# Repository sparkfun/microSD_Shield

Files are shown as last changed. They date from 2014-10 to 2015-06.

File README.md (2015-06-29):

SparkFun microSD Shield
===========================

microSD Shield

[*microSD Shield (DEV-12761)*](https://www.sparkfun.com/products/12761)

The microSD shield equips your Arduino with mass-storage capability, so you can use it for data-logging or other related projects. 

Repository Contents
-------------------

* **/Firmware** - Example .INO sketch for Arduino. Requires the SD.h library
* **/Hardware** - All Eagle design files (.brd, .sch)
* **/Production** - Test bed files and production panel files

Documentation
--------------
* **[Hookup Guide](https://learn.sparkfun.com/tutorials/microsd-shield-and-sd-breakout-hookup-guide)** - Basic hookup guide for the microSD Shield.
* **[SparkFun Fritzing repo](https://github.com/sparkfun/Fritzing_Parts)** - Fritzing diagrams for SparkFun products.
* **[SparkFun 3D Model repo](https://github.com/sparkfun/3D_Models)** - 3D models of SparkFun products. 

Product Versions
----------------
* [DEV-09802](https://www.sparkfun.com/products/9802)- Hardware version 1.3. Designed for Uno (not R3)

Version History
---------------
* [v1.3](https://github.com/sparkfun/microSD_Shield/tree/V_1.3) Version 1.3

License Information
-------------------

This product is _**open source**_! 

Please review the LICENSE.md file for license information. 

If you have any questions or concerns on licensing, please contact techsupport@sparkfun.com.

Distributed as-is; no warranty is given.

- Your friends at SparkFun.

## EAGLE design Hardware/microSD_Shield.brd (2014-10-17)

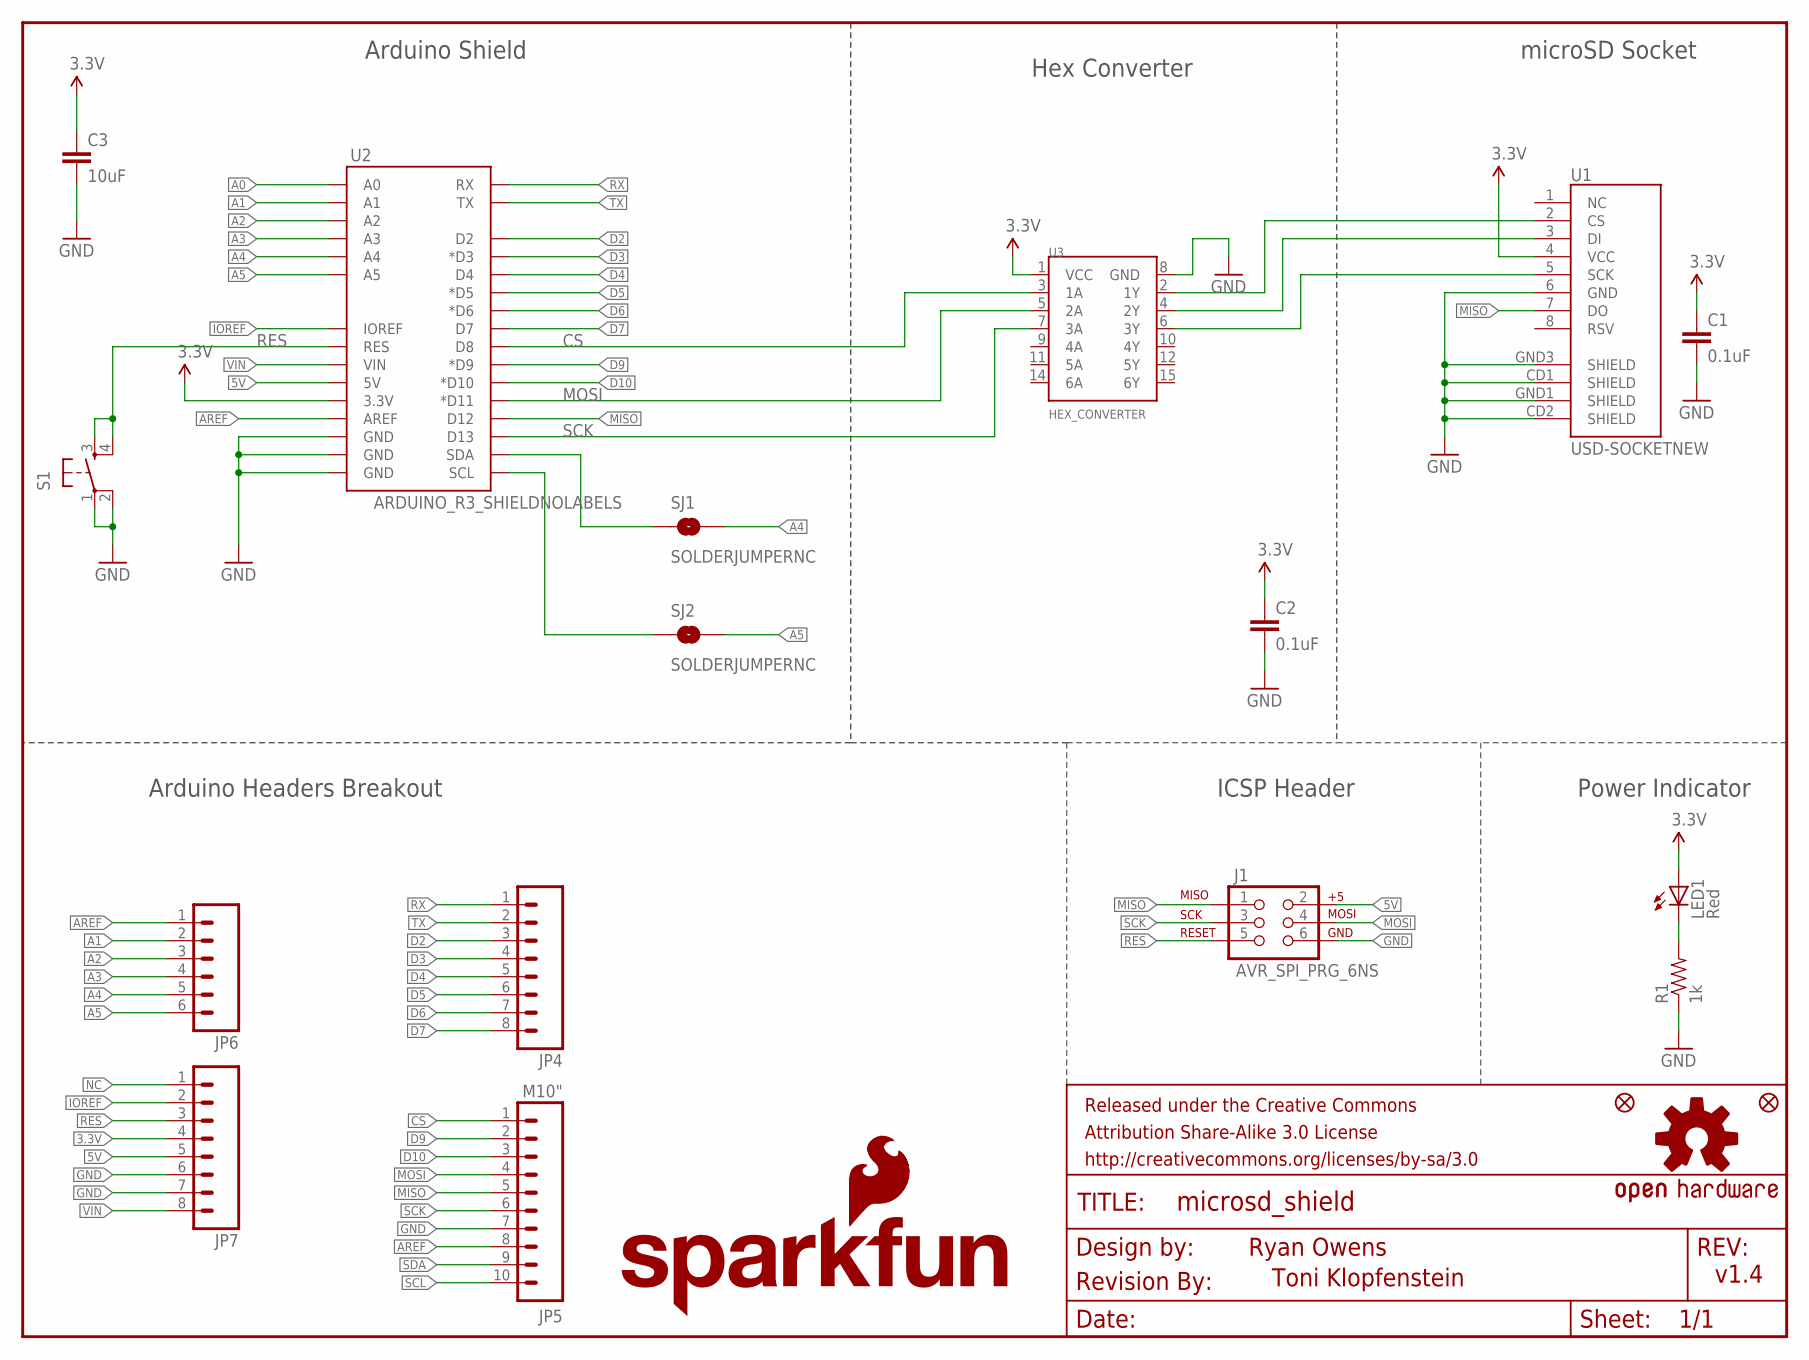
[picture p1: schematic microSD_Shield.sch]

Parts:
C1, C2: 0.1uF; 0603-CAP
C3: 10uF; 0603-CAP
FRAME1: FRAME-LETTER; CREATIVE_COMMONS
J1: AVR_SPI_PRG_6NS; 2X3-NS
JP1: SFE_LOGO_NAME_FLAME.1_INCH; SFE_LOGO_NAME_FLAME_.1
JP2, JP3: FIDUCIAL1X2; FIDUCIAL-1X2
JP4: M08; 1X08
JP5: M10"; 1X10
JP6: M06SIP; 1X06
JP7: M081X08; 1X08
LED1: Red; LED-0603
LOGO1: OSHW-LOGOM; OSHW-LOGO-M
LOGO2: SFE_LOGO_FLAME.6_INCH; SFE_LOGO_FLAME_.6
R1: 1k; 0603-RES
S1: TAC_SWITCHSMD; TACTILE_SWITCH_SMD
SJ1, SJ2: SOLDERJUMPERNC; SJ_2S
U1: USD-SOCKETNEW; MICRO-SD-SOCKET-PP
U2: ARDUINO_R3_SHIELDNOLABELS; UNO_R3_SHIELD_NOLABELS
U3: HEX_CONVERTER; SO016
U$1: REVISION

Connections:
3.3V: C1.1, C2.1, C3.1, JP7.4, LED1.A, U1.4 (VCC), U2.3.3V, U3.1 (VCC)
5V: J1.2, JP7.5, U2.5V
A0: JP6.1, U2.A0
A1: JP6.2, U2.A1
A2: JP6.3, U2.A2
A3: JP6.4, U2.A3
A4: JP6.5, SJ1.2, U2.A4
A5: JP6.6, SJ2.2, U2.A5
AREF: JP5.8, U2.AREF
CS: JP5.1, U2.D8, U3.3 (1A)
D2: JP4.3, U2.D2
D3: JP4.4, U2.D3 (*D3)
D4: JP4.5, U2.D4
D5: JP4.6, U2.D5 (*D5)
D6: JP4.7, U2.D6 (*D6)
D7: JP4.8, U2.D7
D9: JP5.2, U2.D9 (*D9)
D10: JP5.3, U2.D10 (*D10)
GND: C1.2, C2.2, C3.2, J1.6, JP5.7, JP7.6, JP7.7, R1.1, S1.1, S1.2, U1.6 (GND), U1.CD1 (SHIELD), U1.CD2 (SHIELD), U1.GND1 (SHIELD), U1.GND3 (SHIELD), U2.GND@0 (GND), U2.GND@1 (GND), U2.GND@2 (GND), U3.8 (GND)
IOREF: JP7.2, U2.IOREF
MISO: J1.1, JP5.5, U1.7 (DO), U2.D12
MOSI: J1.4, JP5.4, U2.D11 (*D11), U3.5 (2A)
unnamed: U1.3 (DI), U3.4 (2Y)
unnamed: U1.5 (SCK), U3.6 (3Y)
unnamed: LED1.C, R1.2
unnamed: U1.2 (CS), U3.2 (1Y)
NC: JP7.1
RES: J1.5, JP7.3, S1.3, S1.4, U2.RES
RX: JP4.1, U2.RX
SCK: J1.3, JP5.6, U2.D13, U3.7 (3A)
SCL: JP5.10, SJ2.1, U2.SCL
SDA: JP5.9, SJ1.1, U2.SDA
TX: JP4.2, U2.TX
VIN: JP7.8, U2.VIN

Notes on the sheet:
Power Indicator
Ryan Owens
v1.4
Toni Klopfenstein
Arduino Headers Breakout
ICSP Header
microSD Socket
Hex Converter
Arduino Shield

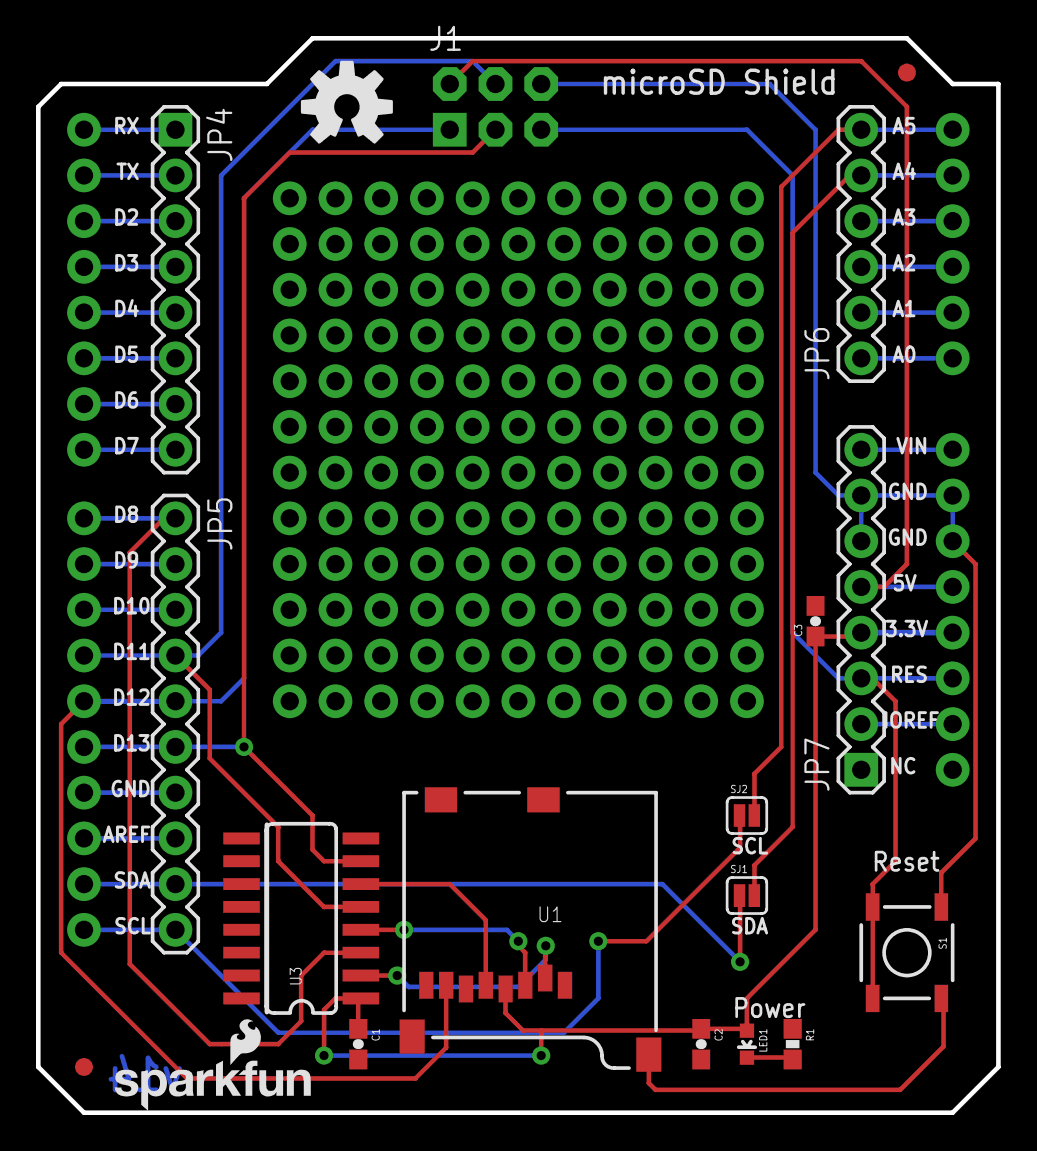
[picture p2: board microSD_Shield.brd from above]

Board: 2 copper layers, 53.3 x 59.7 mm, 23 parts (1 on the bottom side), 33 nets.

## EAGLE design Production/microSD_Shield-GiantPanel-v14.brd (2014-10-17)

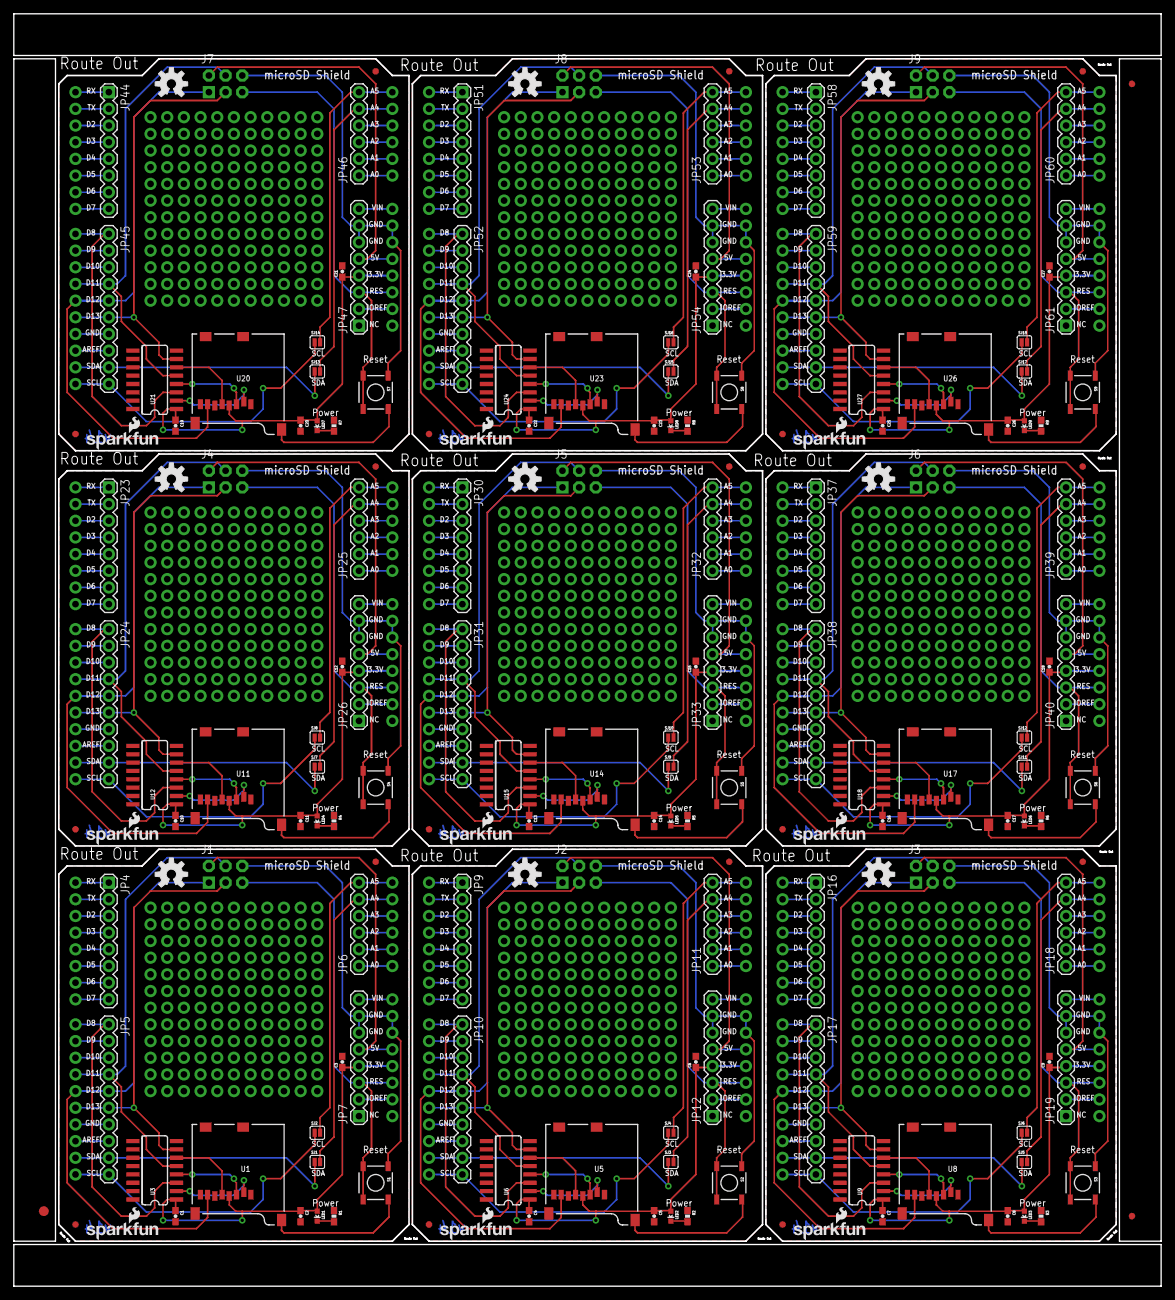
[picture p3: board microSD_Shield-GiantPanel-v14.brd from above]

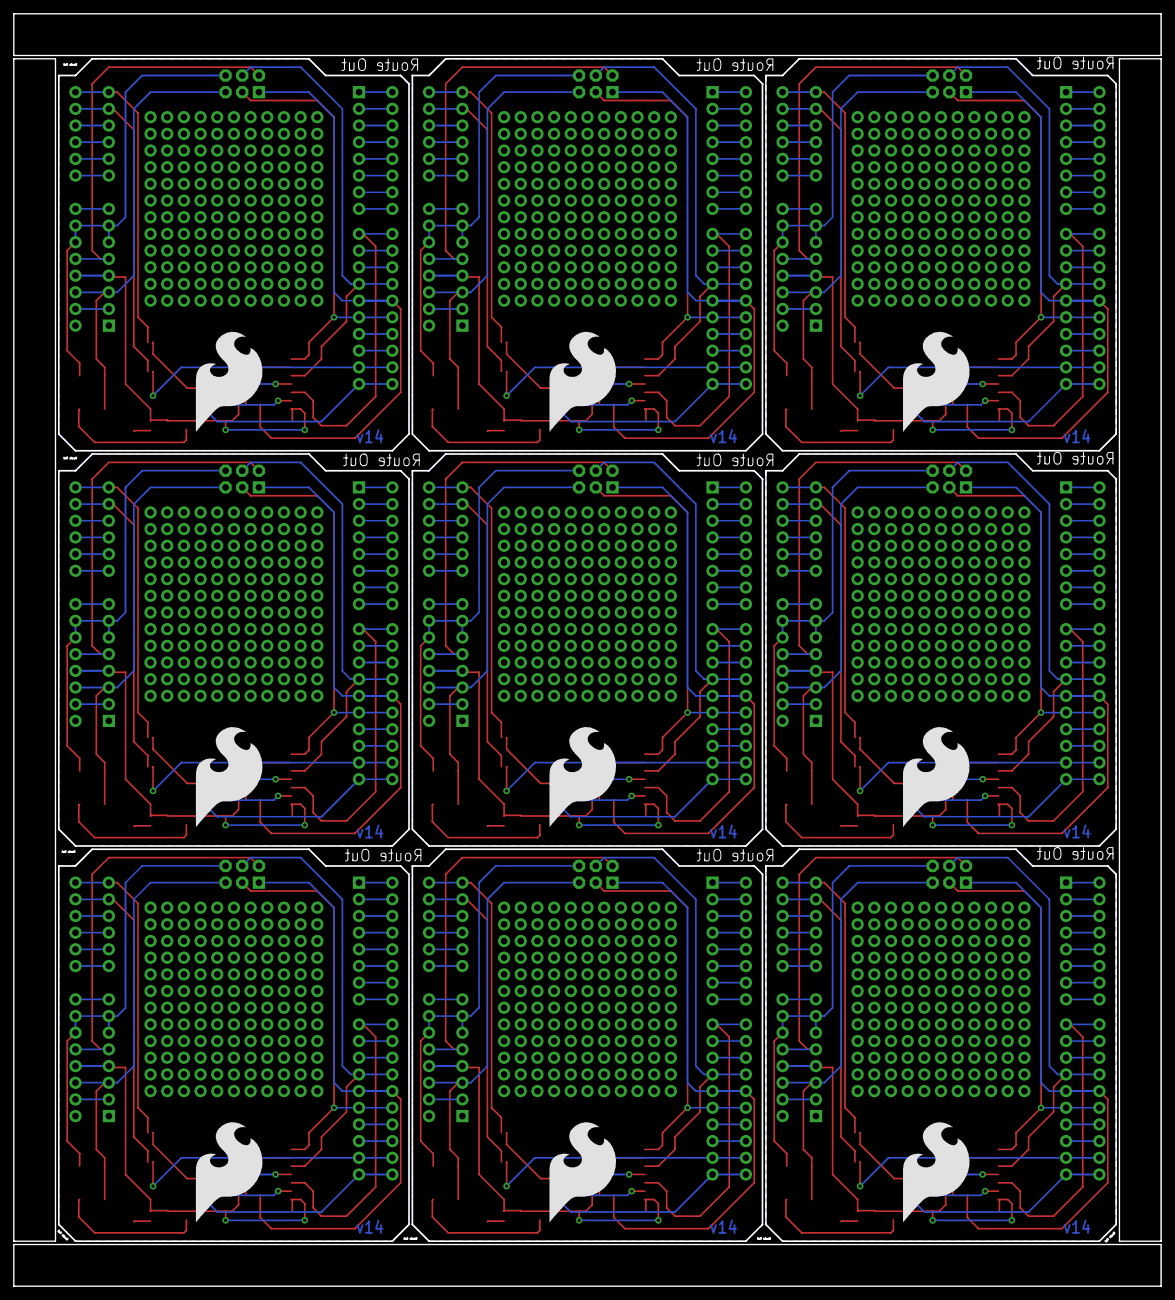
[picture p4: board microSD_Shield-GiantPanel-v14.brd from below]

Board: 2 copper layers, 174.8 x 193.8 mm, 192 parts (9 on the bottom side), 297 nets.

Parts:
C1, C2, C4, C5, C7, C8, C10, C11, C13, C14, C16, C17, C19, C20, C22, C23, C25, C26: 0.1uF; 0603-CAP
C3, C6, C9, C12, C15, C18, C21, C24, C27: 10uF; 0603-CAP
E$1: FIDUCIAL-1.5X3
E$6, E$8: FIDUCIAL-1X2
J1, J2, J3, J4, J5, J6, J7, J8, J9: AVR_SPI_PRG_6NS; 2X3-NS
JP1, JP8, JP15, JP22, JP29, JP36, JP43, JP50, JP57: SFE_LOGO_NAME_FLAME.1_INCH; SFE_LOGO_NAME_FLAME_.1
JP2, JP3, JP13, JP14, JP20, JP21, JP27, JP28, JP34, JP35, JP41, JP42, JP48, JP49, JP55, JP56, JP62, JP63: FIDUCIAL1X2; FIDUCIAL-1X2
JP4, JP7, JP9, JP12, JP16, JP19, JP23, JP26, JP30, JP33, JP37, JP40, JP44, JP47, JP51, JP54, JP58, JP61: 1X08
JP5, JP10, JP17, JP24, JP31, JP38, JP45, JP52, JP59: M10"; 1X10
JP6, JP11, JP18, JP25, JP32, JP39, JP46, JP53, JP60: 1X06
LED1, LED2, LED3, LED4, LED5, LED6, LED7, LED8, LED9: Red; LED-0603
LOGO1, LOGO3, LOGO5, LOGO7, LOGO9, LOGO11, LOGO13, LOGO15, LOGO17: OSHW-LOGOM; OSHW-LOGO-M
LOGO2, LOGO4, LOGO6, LOGO8, LOGO10, LOGO12, LOGO14, LOGO16, LOGO18: SFE_LOGO_FLAME.6_INCH; SFE_LOGO_FLAME_.6
R1, R2, R3, R4, R5, R6, R7, R8, R9: 1k; 0603-RES
S1, S2, S3, S4, S5, S6, S7, S8, S9: TACTILE_SWITCH_SMD
SJ1, SJ2, SJ3, SJ4, SJ5, SJ6, SJ7, SJ8, SJ9, SJ10, SJ11, SJ12, SJ13, SJ14, SJ15, SJ16, SJ17, SJ18: SOLDERJUMPERNC; SJ_2S
U1, U5, U8, U11, U14, U17, U20, U23, U26: USD-SOCKETNEW; MICRO-SD-SOCKET-PP
U2, U4, U7, U10, U13, U16, U19, U22, U25: ARDUINO_R3_SHIELDNOLABELS; UNO_R3_SHIELD_NOLABELS
U3, U6, U9, U12, U15, U18, U21, U24, U27: HEX_CONVERTER; SO016

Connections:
3.3V: C1.1, C2.1, C3.1, JP7.4, LED1.A, U1.4, U2.3.3V, U3.1
3.3V1: C4.1, C5.1, C6.1, JP12.4, LED2.A, U4.3.3V, U5.4, U6.1
3.3V2: C7.1, C8.1, C9.1, JP19.4, LED3.A, U7.3.3V, U8.4, U9.1
3.3V3: C10.1, C11.1, C12.1, JP26.4, LED4.A, U10.3.3V, U11.4, U12.1
3.3V4: C13.1, C14.1, C15.1, JP33.4, LED5.A, U13.3.3V, U14.4, U15.1
3.3V5: C16.1, C17.1, C18.1, JP40.4, LED6.A, U16.3.3V, U17.4, U18.1
3.3V6: C19.1, C20.1, C21.1, JP47.4, LED7.A, U19.3.3V, U20.4, U21.1
3.3V7: C22.1, C23.1, C24.1, JP54.4, LED8.A, U22.3.3V, U23.4, U24.1
3.3V8: C25.1, C26.1, C27.1, JP61.4, LED9.A, U25.3.3V, U26.4, U27.1
5V: J1.2, JP7.5, U2.5V
5V1: J2.2, JP12.5, U4.5V
5V2: J3.2, JP19.5, U7.5V
5V3: J4.2, JP26.5, U10.5V
5V4: J5.2, JP33.5, U13.5V
5V5: J6.2, JP40.5, U16.5V
5V6: J7.2, JP47.5, U19.5V
5V7: J8.2, JP54.5, U22.5V
5V8: J9.2, JP61.5, U25.5V
A0: JP6.1, U2.A0
A1: JP6.2, U2.A1
A2: JP6.3, U2.A2
A3: JP6.4, U2.A3
A4: JP6.5, SJ1.2, U2.A4
A5: JP6.6, SJ2.2, U2.A5
A6: JP11.1, U4.A0
A7: JP11.2, U4.A1
A8: JP11.3, U4.A2
A9: JP11.4, U4.A3
A10: JP11.5, SJ3.2, U4.A4
A11: JP11.6, SJ4.2, U4.A5
A12: JP18.1, U7.A0
A13: JP18.2, U7.A1
A14: JP18.3, U7.A2
A15: JP18.4, U7.A3
A16: JP18.5, SJ5.2, U7.A4
A17: JP18.6, SJ6.2, U7.A5
A18: JP25.1, U10.A0
A19: JP25.2, U10.A1
A20: JP25.3, U10.A2
A21: JP25.4, U10.A3
A22: JP25.5, SJ7.2, U10.A4
A23: JP25.6, SJ8.2, U10.A5
A24: JP32.1, U13.A0
A25: JP32.2, U13.A1
A26: JP32.3, U13.A2
A27: JP32.4, U13.A3
A28: JP32.5, SJ9.2, U13.A4
A29: JP32.6, SJ10.2, U13.A5
A30: JP39.1, U16.A0
A31: JP39.2, U16.A1
A32: JP39.3, U16.A2
A33: JP39.4, U16.A3
A34: JP39.5, SJ11.2, U16.A4
A35: JP39.6, SJ12.2, U16.A5
A36: JP46.1, U19.A0
A37: JP46.2, U19.A1
A38: JP46.3, U19.A2
A39: JP46.4, U19.A3
A40: JP46.5, SJ13.2, U19.A4
A41: JP46.6, SJ14.2, U19.A5
A42: JP53.1, U22.A0
A43: JP53.2, U22.A1
A44: JP53.3, U22.A2
A45: JP53.4, U22.A3
A46: JP53.5, SJ15.2, U22.A4
A47: JP53.6, SJ16.2, U22.A5
A48: JP60.1, U25.A0
A49: JP60.2, U25.A1
A50: JP60.3, U25.A2
A51: JP60.4, U25.A3
A52: JP60.5, SJ17.2, U25.A4
A53: JP60.6, SJ18.2, U25.A5
AREF: JP5.8, U2.AREF
AREF1: JP10.8, U4.AREF
AREF2: JP17.8, U7.AREF
AREF3: JP24.8, U10.AREF
AREF4: JP31.8, U13.AREF
AREF5: JP38.8, U16.AREF
AREF6: JP45.8, U19.AREF
AREF7: JP52.8, U22.AREF
AREF8: JP59.8, U25.AREF
CS: JP5.1, U2.D8, U3.3
CS1: JP10.1, U4.D8, U6.3
CS2: JP17.1, U7.D8, U9.3
CS3: JP24.1, U10.D8, U12.3
CS4: JP31.1, U13.D8, U15.3
CS5: JP38.1, U16.D8, U18.3
CS6: JP45.1, U19.D8, U21.3
CS7: JP52.1, U22.D8, U24.3
CS8: JP59.1, U25.D8, U27.3
D1: JP9.3, U4.D2
D2: JP4.3, U2.D2
D3: JP4.4, U2.D3
D4: JP4.5, U2.D4
D5: JP4.6, U2.D5
D6: JP4.7, U2.D6
D7: JP4.8, U2.D7
D8: JP9.4, U4.D3
D9: JP5.2, U2.D9
D10: JP5.3, U2.D10
D11: JP9.5, U4.D4
D12: JP9.6, U4.D5
D13: JP9.7, U4.D6
D14: JP9.8, U4.D7
D15: JP10.2, U4.D9
D16: JP10.3, U4.D10
D17: JP16.3, U7.D2
D18: JP16.4, U7.D3
D19: JP16.5, U7.D4
D20: JP16.6, U7.D5
D21: JP16.7, U7.D6
D22: JP16.8, U7.D7
D23: JP17.2, U7.D9
D24: JP17.3, U7.D10
D25: JP23.3, U10.D2
D26: JP23.4, U10.D3
D27: JP23.5, U10.D4
D28: JP23.6, U10.D5
D29: JP23.7, U10.D6
D30: JP23.8, U10.D7
D31: JP24.2, U10.D9
D32: JP24.3, U10.D10
D33: JP30.3, U13.D2
D34: JP30.4, U13.D3
D35: JP30.5, U13.D4
D36: JP30.6, U13.D5
D37: JP30.7, U13.D6
D38: JP30.8, U13.D7
D39: JP31.2, U13.D9
D40: JP31.3, U13.D10
D41: JP37.3, U16.D2
D42: JP37.4, U16.D3
D43: JP37.5, U16.D4
D44: JP37.6, U16.D5
D45: JP37.7, U16.D6
D46: JP37.8, U16.D7
D47: JP38.2, U16.D9
D48: JP38.3, U16.D10
D49: JP44.3, U19.D2
D50: JP44.4, U19.D3
D51: JP44.5, U19.D4
D52: JP44.6, U19.D5
D53: JP44.7, U19.D6
D54: JP44.8, U19.D7
D55: JP45.2, U19.D9
D56: JP45.3, U19.D10
D57: JP51.3, U22.D2
D58: JP51.4, U22.D3
D59: JP51.5, U22.D4
D60: JP51.6, U22.D5
D61: JP51.7, U22.D6
D62: JP51.8, U22.D7
D63: JP52.2, U22.D9
D64: JP52.3, U22.D10
D65: JP58.3, U25.D2
D66: JP58.4, U25.D3
D67: JP58.5, U25.D4
D68: JP58.6, U25.D5
D69: JP58.7, U25.D6
D70: JP58.8, U25.D7
D71: JP59.2, U25.D9
D72: JP59.3, U25.D10
GND: C1.2, C2.2, C3.2, J1.6, JP5.7, JP7.6, JP7.7, R1.1, S1.1, S1.2, U1.6, U1.CD1, U1.CD2, U1.GND1, U1.GND3, U2.GND@0, U2.GND@1, U2.GND@2, U3.8
GND1: C4.2, C5.2, C6.2, J2.6, JP10.7, JP12.6, JP12.7, R2.1, S2.1, S2.2, U4.GND@0, U4.GND@1, U4.GND@2, U5.6, U5.CD1, U5.CD2, U5.GND1, U5.GND3, U6.8
GND2: C7.2, C8.2, C9.2, J3.6, JP17.7, JP19.6, JP19.7, R3.1, S3.1, S3.2, U7.GND@0, U7.GND@1, U7.GND@2, U8.6, U8.CD1, U8.CD2, U8.GND1, U8.GND3, U9.8
GND3: C10.2, C11.2, C12.2, J4.6, JP24.7, JP26.6, JP26.7, R4.1, S4.1, S4.2, U10.GND@0, U10.GND@1, U10.GND@2, U11.6, U11.CD1, U11.CD2, U11.GND1, U11.GND3, U12.8
GND4: C13.2, C14.2, C15.2, J5.6, JP31.7, JP33.6, JP33.7, R5.1, S5.1, S5.2, U13.GND@0, U13.GND@1, U13.GND@2, U14.6, U14.CD1, U14.CD2, U14.GND1, U14.GND3, U15.8
GND5: C16.2, C17.2, C18.2, J6.6, JP38.7, JP40.6, JP40.7, R6.1, S6.1, S6.2, U16.GND@0, U16.GND@1, U16.GND@2, U17.6, U17.CD1, U17.CD2, U17.GND1, U17.GND3, U18.8
GND6: C19.2, C20.2, C21.2, J7.6, JP45.7, JP47.6, JP47.7, R7.1, S7.1, S7.2, U19.GND@0, U19.GND@1, U19.GND@2, U20.6, U20.CD1, U20.CD2, U20.GND1, U20.GND3, U21.8
GND7: C22.2, C23.2, C24.2, J8.6, JP52.7, JP54.6, JP54.7, R8.1, S8.1, S8.2, U22.GND@0, U22.GND@1, U22.GND@2, U23.6, U23.CD1, U23.CD2, U23.GND1, U23.GND3, U24.8
GND8: C25.2, C26.2, C27.2, J9.6, JP59.7, JP61.6, JP61.7, R9.1, S9.1, S9.2, U25.GND@0, U25.GND@1, U25.GND@2, U26.6, U26.CD1, U26.CD2, U26.GND1, U26.GND3, U27.8
IOREF: JP7.2, U2.IOREF
IOREF1: JP12.2, U4.IOREF
IOREF2: JP19.2, U7.IOREF
IOREF3: JP26.2, U10.IOREF
IOREF4: JP33.2, U13.IOREF
IOREF5: JP40.2, U16.IOREF
IOREF6: JP47.2, U19.IOREF
IOREF7: JP54.2, U22.IOREF
IOREF8: JP61.2, U25.IOREF
MISO: J1.1, JP5.5, U1.7, U2.D12
MISO1: J2.1, JP10.5, U4.D12, U5.7
MISO2: J3.1, JP17.5, U7.D12, U8.7
MISO3: J4.1, JP24.5, U10.D12, U11.7
MISO4: J5.1, JP31.5, U13.D12, U14.7
MISO5: J6.1, JP38.5, U16.D12, U17.7
MISO6: J7.1, JP45.5, U19.D12, U20.7
MISO7: J8.1, JP52.5, U22.D12, U23.7
MISO8: J9.1, JP59.5, U25.D12, U26.7
MOSI: J1.4, JP5.4, U2.D11, U3.5
MOSI1: J2.4, JP10.4, U4.D11, U6.5
MOSI2: J3.4, JP17.4, U7.D11, U9.5
MOSI3: J4.4, JP24.4, U10.D11, U12.5
MOSI4: J5.4, JP31.4, U13.D11, U15.5
MOSI5: J6.4, JP38.4, U16.D11, U18.5
MOSI6: J7.4, JP45.4, U19.D11, U21.5
MOSI7: J8.4, JP52.4, U22.D11, U24.5
MOSI8: J9.4, JP59.4, U25.D11, U27.5
unnamed: U5.3, U6.4
unnamed: U1.3, U3.4
unnamed: LED2.C, R2.2
unnamed: U1.5, U3.6
unnamed: LED1.C, R1.2
unnamed: U1.2, U3.2
unnamed: U5.2, U6.2
unnamed: U5.5, U6.6
unnamed: U8.3, U9.4
unnamed: LED3.C, R3.2
unnamed: U8.2, U9.2
unnamed: U8.5, U9.6
unnamed: U11.3, U12.4
unnamed: LED4.C, R4.2
unnamed: U11.2, U12.2
unnamed: U11.5, U12.6
unnamed: U14.3, U15.4
unnamed: LED5.C, R5.2
unnamed: U14.2, U15.2
unnamed: U14.5, U15.6
unnamed: U17.3, U18.4
unnamed: LED6.C, R6.2
unnamed: U17.2, U18.2
unnamed: U17.5, U18.6
unnamed: U20.3, U21.4
unnamed: LED7.C, R7.2
unnamed: U20.2, U21.2
unnamed: U20.5, U21.6
unnamed: U23.3, U24.4
unnamed: LED8.C, R8.2
unnamed: U23.2, U24.2
unnamed: U23.5, U24.6
unnamed: U26.3, U27.4
unnamed: LED9.C, R9.2
unnamed: U26.2, U27.2
unnamed: U26.5, U27.6
RES: J1.5, JP7.3, S1.3, S1.4, U2.RES
RES1: J2.5, JP12.3, S2.3, S2.4, U4.RES
RES2: J3.5, JP19.3, S3.3, S3.4, U7.RES
RES3: J4.5, JP26.3, S4.3, S4.4, U10.RES
RES4: J5.5, JP33.3, S5.3, S5.4, U13.RES
RES5: J6.5, JP40.3, S6.3, S6.4, U16.RES
RES6: J7.5, JP47.3, S7.3, S7.4, U19.RES
RES7: J8.5, JP54.3, S8.3, S8.4, U22.RES
RES8: J9.5, JP61.3, S9.3, S9.4, U25.RES
RX: JP4.1, U2.RX
RX1: JP9.1, U4.RX
RX2: JP16.1, U7.RX
RX3: JP23.1, U10.RX
RX4: JP30.1, U13.RX
RX5: JP37.1, U16.RX
RX6: JP44.1, U19.RX
RX7: JP51.1, U22.RX
RX8: JP58.1, U25.RX
SCK: J1.3, JP5.6, U2.D13, U3.7
SCK1: J2.3, JP10.6, U4.D13, U6.7
SCK2: J3.3, JP17.6, U7.D13, U9.7
SCK3: J4.3, JP24.6, U10.D13, U12.7
SCK4: J5.3, JP31.6, U13.D13, U15.7
SCK5: J6.3, JP38.6, U16.D13, U18.7
SCK6: J7.3, JP45.6, U19.D13, U21.7
SCK7: J8.3, JP52.6, U22.D13, U24.7
SCK8: J9.3, JP59.6, U25.D13, U27.7
SCL: JP5.10, SJ2.1, U2.SCL
SCL1: JP10.10, SJ4.1, U4.SCL
SCL2: JP17.10, SJ6.1, U7.SCL
SCL3: JP24.10, SJ8.1, U10.SCL
SCL4: JP31.10, SJ10.1, U13.SCL
SCL5: JP38.10, SJ12.1, U16.SCL
SCL6: JP45.10, SJ14.1, U19.SCL
SCL7: JP52.10, SJ16.1, U22.SCL
SCL8: JP59.10, SJ18.1, U25.SCL
SDA: JP5.9, SJ1.1, U2.SDA
SDA1: JP10.9, SJ3.1, U4.SDA
SDA2: JP17.9, SJ5.1, U7.SDA
SDA3: JP24.9, SJ7.1, U10.SDA
SDA4: JP31.9, SJ9.1, U13.SDA
SDA5: JP38.9, SJ11.1, U16.SDA
SDA6: JP45.9, SJ13.1, U19.SDA
SDA7: JP52.9, SJ15.1, U22.SDA
SDA8: JP59.9, SJ17.1, U25.SDA
TX: JP4.2, U2.TX
TX1: JP9.2, U4.TX
TX2: JP16.2, U7.TX
TX3: JP23.2, U10.TX
TX4: JP30.2, U13.TX
TX5: JP37.2, U16.TX
TX6: JP44.2, U19.TX
TX7: JP51.2, U22.TX
TX8: JP58.2, U25.TX
VIN: JP7.8, U2.VIN
VIN1: JP12.8, U4.VIN
VIN2: JP19.8, U7.VIN
VIN3: JP26.8, U10.VIN
VIN4: JP33.8, U13.VIN
VIN5: JP40.8, U16.VIN
VIN6: JP47.8, U19.VIN
VIN7: JP54.8, U22.VIN
VIN8: JP61.8, U25.VIN

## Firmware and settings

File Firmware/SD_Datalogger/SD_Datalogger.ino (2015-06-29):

/*
 created 24 Nov 2010
 modified 9 Apr 2012
 by Tom Igoe
 
 modified 18 Sep 2014
 by Bobby Chan @ SparkFun Electronics Inc.

 modified 26 Jun 2015
 by Charles Galant
 
 SD Card Datalogger
 
 This example is based off an example code from Arduino's site
 http://arduino.cc/en/Tutorial/Datalogger and it shows how to 
 log data from three analog sensors with a timestamp based on when
 the Arduino began running the current program to an SD card using
 the SD library https://github.com/greiman/SdFat by William 
 Greiman. This example code also includes an output to the 
 Serial Monitor for debugging.
 	
 The circuit:
 * analog sensors on analog pins 0, 1, and 2
 * SD card attached to SPI bus as follows:
 ** MOSI - pin 11
 ** MISO - pin 12
 ** CLK - pin 13
 ** CS - pin 8
 
 This example code is in the public domain.
 */


#include <SD.h>
#include <SPI.h>

// On the Ethernet Shield, CS is pin 4. Note that even if it's not
// used as the CS pin, the hardware CS pin (10 on most Arduino boards,
// 53 on the Mega) must be left as an output or the SD library
// functions will not work.

// Chip Select pin is tied to pin 8 on the SparkFun SD Card Shield
const int chipSelect = 8;  

void setup()
{
  // Open serial communications and wait for port to open:
  Serial.begin(9600);
  while (!Serial) {
    ; // wait for serial port to connect. Needed for Leonardo only
  }

  Serial.print("Initializing SD card...");
  // make sure that the default chip select pin is set to
  // output, even if you don't use it:
  pinMode(chipSelect, OUTPUT);

  // see if the card is present and can be initialized:
  if (!SD.begin(chipSelect)) {
    Serial.println("Card failed, or not present");
    // don't do anything more:
    return;
  }
  Serial.println("card initialized.");
}

void loop()
{

  // open the file. note that only one file can be open at a time,
  // so you have to close this one before opening another.
  // this opens the file and appends to the end of file
  // if the file does not exist, this will create a new file.
  File dataFile = SD.open("datalog.txt", FILE_WRITE);

  // if the file is available, write to it:
  if (dataFile)   {  
    unsigned long timeStamp = millis();
    //write to uSD card
    dataFile.print(timeStamp);
    dataFile.print(" ms");
    dataFile.print(", ");
    //output also on Serial monitor for debugging
    Serial.print(timeStamp);
    Serial.print(" ms");
    Serial.print(",");

    // read three sensors on A0, A1, and A2 while appending to the string:
    for (int analogPin = 0; analogPin < 3; analogPin++) 
    {
      int sensorVal = analogRead(analogPin);
      //write analog sensor data to uSD card
      dataFile.print("Analog Pin A");
      dataFile.print(analogPin);
      dataFile.print(" = ");
      dataFile.print(sensorVal);
      //output also on Serial monitor for debugging
      Serial.print(" Analog Pin A");
      Serial.print(analogPin);
      Serial.print(" = ");
      Serial.print(sensorVal);
      //place comma between the analog sensor data
      if (analogPin < 2) 
      {
        dataFile.print(", ");
		Serial.print(", ");
      }
    }
    dataFile.println(); //create a new row to read data more clearly
    dataFile.close();   //close file
    Serial.println();   //print to the serial port too:

  }  
  // if the file isn't open, pop up an error:
  else
  {
    Serial.println("error opening datalog.txt");
  } 
}

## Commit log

2014-02-11 Initial board file commit
    [microSD_Shield-v13.brd, microSD_Shield-v13.sch]
2014-02-12 Adding v1.4 board files
    [microSD_Shield-v13.brd, microSD_Shield-v13.sch, microSD_Shield.brd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]
2014-02-25 Adding decoupling capacitors
    [microSD_Shield.brd, microSD_Shield.sch]
2014-02-28 Adding bottom flame to pcb
    [microSD_Shield.brd, microSD_Shield.sch]
2014-04-17 Upping back flame size
    [microSD_Shield.brd, microSD_Shield.sch]
2014-04-18 created giant panel v14
    [microSD_Shield-GiantPanel-v14.brd]
2014-09-18 Firmware Update for SD_Datalogger.ino
    1.) Missing a line to create a string so the sketch won't compile in Arduino.
    2.) Added links the original example code from Arduino and SD library on GitHub by William Greiman.
    3.) Includes some outputs to the Serial Monitor for debugging.
    [SD_Datalogger.ino]
2015-06-26 Various fixes
    Updated description to correct CS pin used in example
    Added include for SPI.h which is required to compile
    Removed unused String and all references thereto
    Fixed incorrect casting of millis() to int, which was causing rollover
    after 37 seconds
    Added label to timestamp serial output for consistency with file
    Removed extra space from output channel labels
    Fixed comma separation which was appending to unused string, now
    correctly applies to outputs
    Removed trailing comma from output
    [SD_Datalogger.ino]
2015-06-29 Fixing directory name, adding license file, updating README
    [microSD_Shield-GiantPanel-v14.brd]

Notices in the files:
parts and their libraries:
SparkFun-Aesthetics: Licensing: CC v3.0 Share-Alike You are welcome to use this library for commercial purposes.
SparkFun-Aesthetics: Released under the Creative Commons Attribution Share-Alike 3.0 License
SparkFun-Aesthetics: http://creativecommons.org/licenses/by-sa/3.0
